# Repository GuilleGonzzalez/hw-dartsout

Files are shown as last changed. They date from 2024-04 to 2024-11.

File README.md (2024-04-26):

# Dartsout

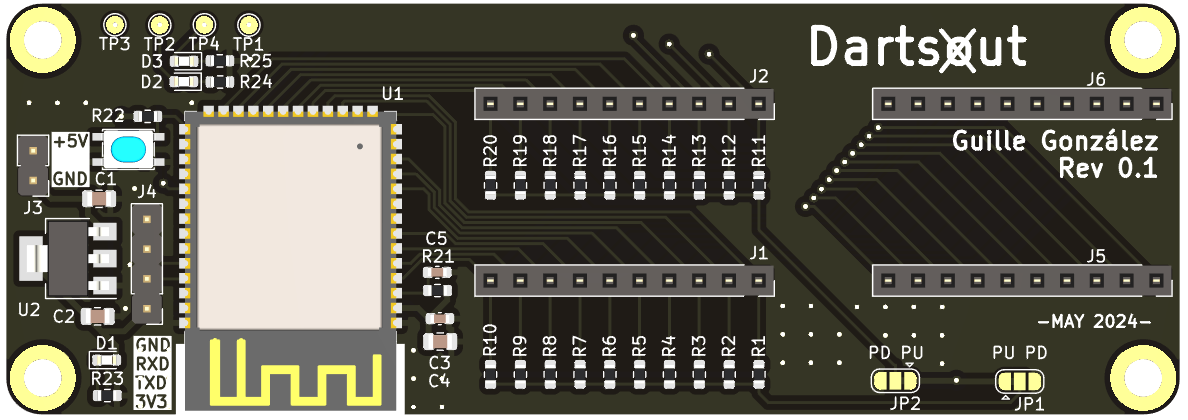
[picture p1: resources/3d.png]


## Description

Dartsout is a pcb designed to replace the control board of commercial dartboards to make them compatible with Dartsout, a darts playing application hosted on a server.

Firmware used in the microcontroller of this device is [dartsout](https://github.com/GuilleGonzzalez/fw-dartsout), writed in C. Is in charge of reading the value pressed by the dart and sending it via WiFi to the Dartsout server.

## Microprocessor

Espressif [ESP32-S2-SOLO](https://www.espressif.com/en/products/modules) module (NRND).

## Connectors

The device has 10-pin connectors with a pitch of 2.54, compatible with the connectors of commercial targets. For the connection, it will be necessary to unsolder the connectors of the target to be modified and solder them on this PCB.

They have been duplicated to be flexible with the target connectors to be modified, as sometimes they are in parallel and sometimes they are on top of each other.

In all cases, pin 1 is the one on the right.

## Pin assignment

| PIN | Func |
| --- | --- |
| GPIO1 | ROW01 |
| GPIO9 | ROW02 |
| GPIO3 | ROW03 |
| GPIO8 | ROW04 |
| GPIO18  | ROW05 |
| GPIO17  | ROW06 |
| GPIO7 | ROW07 |
| GPIO6 | ROW08 |
| GPIO5 | ROW09 |
| GPIO4 | ROW10 |
| GPIO37  | COL01 |
| GPIO36  | COL02 |
| GPIO35  | COL03 |
| GPIO34  | COL04 |
| GPIO33  | COL05 |
| GPIO21  | COL06 |
| GPIO14  | COL07 |
| GPIO13  | COL08 |
| GPIO12  | COL09 |
| GPIO11  | COL10 |
| GPIO11  | COL10 |
| GPIO1 | USER LED 1 |
| GPIO2 | USER LED 2 |

## LEDs

This PCB has 3 LEDs:

- One power LED, indicating that the device is on.
- Two for user control.

# Changelog

All notable changes to this project will be documented in this section.

The format is based on [Keep a Changelog](https://keepachangelog.com/en/1.0.0/)

## [v0.1.0] - 2024-04-26
### Add
First Dartsout version.

## [unreleased] - 2024-04-24

[unreleased]: https://github.com/GuilleGonzzalez/hw-dartsout

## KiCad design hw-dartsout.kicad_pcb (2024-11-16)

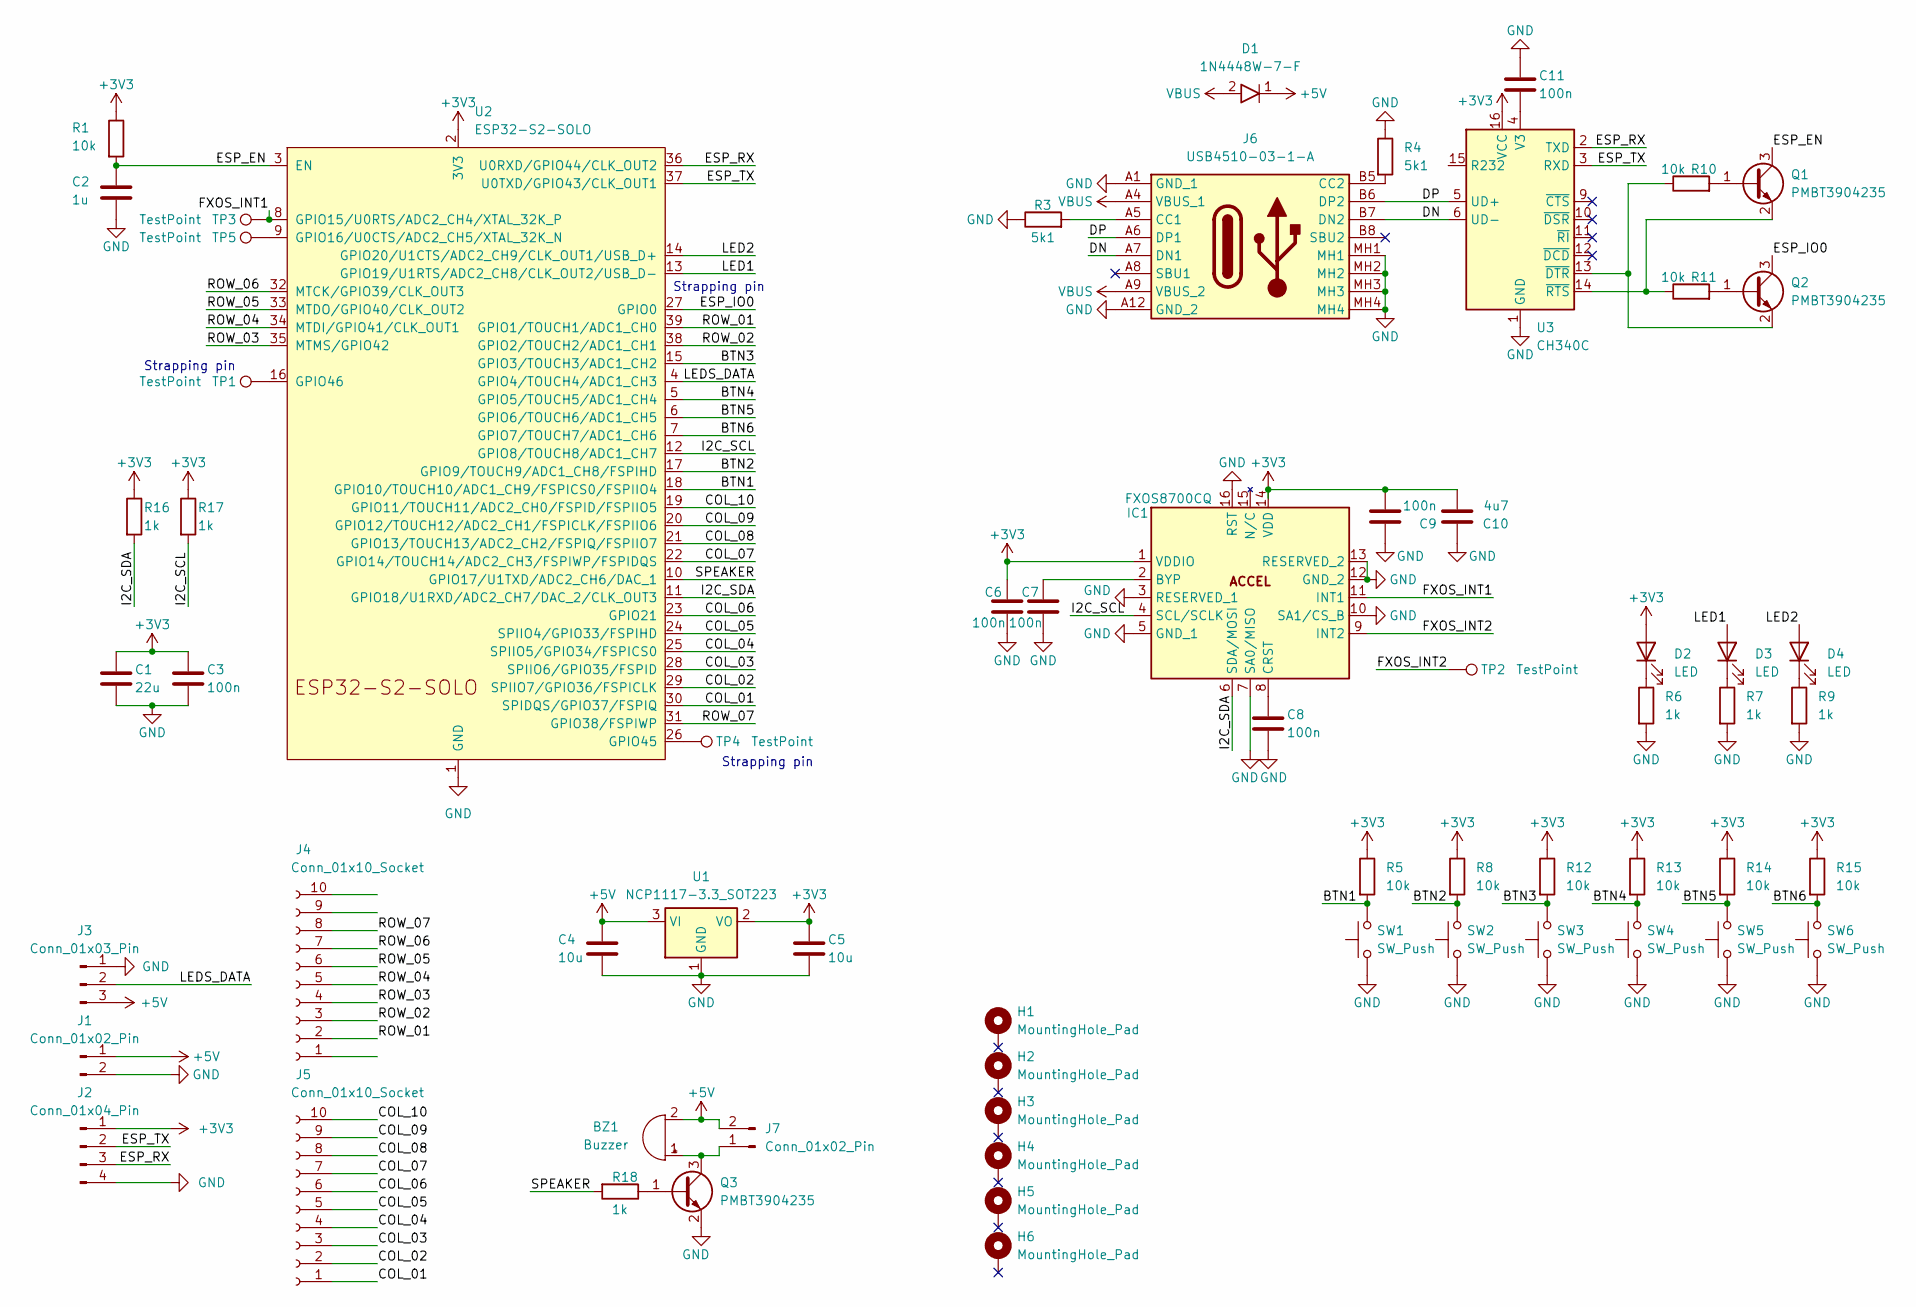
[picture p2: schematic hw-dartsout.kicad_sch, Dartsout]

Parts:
BZ1: Buzzer; Buzzer_12x9.5RM7.6
C1: 22u; C_0805_2012Metric
C2: 1u; C_0603_1608Metric
C3, C6, C7, C8, C9, C11: 100n; C_0603_1608Metric
C4, C5: 10u; C_0805_2012Metric
C10: 4u7; C_0805_2012Metric
D1: 1N4448W-7-F; D_SOD-123; Manufacturer_Part_Number 1N4448W-7-F; Mouser Part Number 621-1N4448W-F
D2, D3, D4: LED; LED_0603_1608Metric
H1, H2, H3, H4, H5, H6: MountingHole_Pad; MountingHole_3.2mm_M3_DIN965_Pad_TopBottom
IC1: FXOS8700CQ; Manufacturer_Part_Number FXOS8700CQ; Mouser Part Number N/A
J1: Conn_01x02_Pin; PinHeader_1x02_P2.54mm_Vertical
J2: Conn_01x04_Pin; PinHeader_1x04_P2.54mm_Vertical
J3: Conn_01x03_Pin; JST_XH_B3B-XH-A_1x03_P2.50mm_Vertical
J4, J5: Conn_01x10_Socket; PinSocket_1x10_P2.54mm_Vertical
J6: USB4510-03-1-A; USB4510031A; Mouser Part Number 640-USB4510031A
J7: Conn_01x02_Pin; PinHeader_1x02_P2.54mm_Horizontal
Q1, Q2, Q3: PMBT3904235; SOT-23; Manufacturer_PN PMBT3904,235
R1, R5, R8, R10, R11, R12, R13, R14, R15: 10k; R_0603_1608Metric
R3, R4: 5k1; R_0603_1608Metric
R6, R7, R9, R16, R17, R18: 1k; R_0603_1608Metric
SW1, SW2, SW3, SW4, SW5, SW6: SW_Push; SW_SPST_PTS810
TP1, TP2, TP3, TP4, TP5: TestPoint; TestPoint_Pad_D1.5mm
U1: NCP1117-3.3_SOT223; SOT-223-3_TabPin2
U2: ESP32-S2-SOLO
U3: CH340C; SOIC-16_3.9x9.9mm_P1.27mm

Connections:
+3V3: C1.1, C3.1, C5.1, C6.1, C9.2, C10.2, D2.2 (A), IC1.1 (VDDIO), IC1.14 (VDD), J2.1, R1.1, R5.1, R8.1, R12.1, R13.1, R14.1, R15.1, R16.1, R17.1, U1.2 (VO), U2.2 (3V3), U3.16 (VCC)
+5V: BZ1.2 (-), C4.1, D1.1, J1.1, J3.3, J7.2, U1.3 (VI)
/BTN1: R5.2, SW1.2, U2.18 (GPIO10/TOUCH10/ADC1_CH9/FSPICS0/FSPIIO4)
/BTN2: R8.2, SW2.2, U2.17 (GPIO9/TOUCH9/ADC1_CH8/FSPIHD)
/BTN3: R12.2, SW3.2, U2.15 (GPIO3/TOUCH3/ADC1_CH2)
/BTN4: R13.2, SW4.2, U2.5 (GPIO5/TOUCH5/ADC1_CH4)
/BTN5: R14.2, SW5.2, U2.6 (GPIO6/TOUCH6/ADC1_CH5)
/BTN6: R15.2, SW6.2, U2.7 (GPIO7/TOUCH7/ADC1_CH6)
/COL_01: J5.1, U2.30 (SPIDQS/GPIO37/FSPIQ)
/COL_02: J5.2, U2.29 (SPIIO7/GPIO36/FSPICLK)
/COL_03: J5.3, U2.28 (SPIIO6/GPIO35/FSPID)
/COL_04: J5.4, U2.25 (SPIIO5/GPIO34/FSPICS0)
/COL_05: J5.5, U2.24 (SPIIO4/GPIO33/FSPIHD)
/COL_06: J5.6, U2.23 (GPIO21)
/COL_07: J5.7, U2.22 (GPIO14/TOUCH14/ADC2_CH3/FSPIWP/FSPIDQS)
/COL_08: J5.8, U2.21 (GPIO13/TOUCH13/ADC2_CH2/FSPIQ/FSPIIO7)
/COL_09: J5.9, U2.20 (GPIO12/TOUCH12/ADC2_CH1/FSPICLK/FSPIIO6)
/COL_10: J5.10, U2.19 (GPIO11/TOUCH11/ADC2_CH0/FSPID/FSPIIO5)
/DN: J6.A7 (DN1), J6.B7 (DN2), U3.6 (UD-)
/DP: J6.A6 (DP1), J6.B6 (DP2), U3.5 (UD+)
/ESP_EN: C2.1, Q1.3, R1.2, U2.3 (EN)
/ESP_IO0: Q2.3, U2.27 (GPIO0)
/ESP_RX: J2.3, U2.36 (U0RXD/GPIO44/CLK_OUT2), U3.2 (TXD)
/ESP_TX: J2.2, U2.37 (U0TXD/GPIO43/CLK_OUT1), U3.3 (RXD)
/FXOS_INT1: IC1.11 (INT1), TP3.1, U2.8 (GPIO15/U0RTS/ADC2_CH4/XTAL_32K_P)
/FXOS_INT2: IC1.9 (INT2), TP2.1
/I2C_SCL: IC1.4 (SCL/SCLK), R17.2, U2.12 (GPIO8/TOUCH8/ADC1_CH7)
/I2C_SDA: IC1.6 (SDA/MOSI), R16.2, U2.11 (GPIO18/U1RXD/ADC2_CH7/DAC_2/CLK_OUT3)
/LED1: D3.2 (A), U2.13 (GPIO19/U1RTS/ADC2_CH8/CLK_OUT2/USB_D-)
/LED2: D4.2 (A), U2.14 (GPIO20/U1CTS/ADC2_CH9/CLK_OUT1/USB_D+)
/LEDS_DATA: J3.2, U2.4 (GPIO4/TOUCH4/ADC1_CH3)
/ROW_01: J4.2, U2.39 (GPIO1/TOUCH1/ADC1_CH0)
/ROW_02: J4.3, U2.38 (GPIO2/TOUCH2/ADC1_CH1)
/ROW_03: J4.4, U2.35 (MTMS/GPIO42)
/ROW_04: J4.5, U2.34 (MTDI/GPIO41/CLK_OUT1)
/ROW_05: J4.6, U2.33 (MTDO/GPIO40/CLK_OUT2)
/ROW_06: J4.7, U2.32 (MTCK/GPIO39/CLK_OUT3)
/ROW_07: J4.8, U2.31 (GPIO38/FSPIWP)
/SPEAKER: R18.2, U2.10 (GPIO17/U1TXD/ADC2_CH6/DAC_1)
GND: C1.2, C2.2, C3.2, C4.2, C5.2, C6.2, C7.1, C8.2, C9.1, C10.1, C11.1, IC1.3 (RESERVED_1), IC1.5 (GND_1), IC1.7 (SA0/MISO), IC1.10 (SA1/CS_B), IC1.12 (GND_2), IC1.13 (RESERVED_2), IC1.16 (RST), J1.2, J2.4, J3.1, J6.A1 (GND_1), J6.A12 (GND_2), J6.MH1, J6.MH2, J6.MH3, J6.MH4, Q3.2, R3.1, R4.1, R6.2, R7.2, R9.2, SW1.1, SW2.1, SW3.1, SW4.1, SW5.1, SW6.1, U1.1 (GND), U2.1 (GND), U2.40 (GND), U2.41 (GND), U3.1 (GND)
unnamed: BZ1.1 (+), J7.1, Q3.3
unnamed: D2.1 (K), R6.1
unnamed: D3.1 (K), R7.1
unnamed: D4.1 (K), R9.1
unnamed: C7.2, IC1.2 (BYP)
unnamed: C8.1, IC1.8 (CRST)
unnamed: J6.A5 (CC1), R3.2
unnamed: J6.B5 (CC2), R4.2
unnamed: Q1.1, R10.2
unnamed: Q2.1, R11.2
unnamed: Q3.1, R18.1
unnamed: TP5.1, U2.9 (GPIO16/U0CTS/ADC2_CH5/XTAL_32K_N)
unnamed: TP4.1, U2.26 (GPIO45)
unnamed: TP1.1, U2.16 (GPIO46)
unnamed: C11.2, U3.4 (V3)
unnamed: Q2.2, R10.1, U3.13 (~DTR)
unnamed: Q1.2, R11.1, U3.14 (~RTS)
VBUS: D1.2, J6.A4 (VBUS_1), J6.A9 (VBUS_2)

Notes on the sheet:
Strapping pin

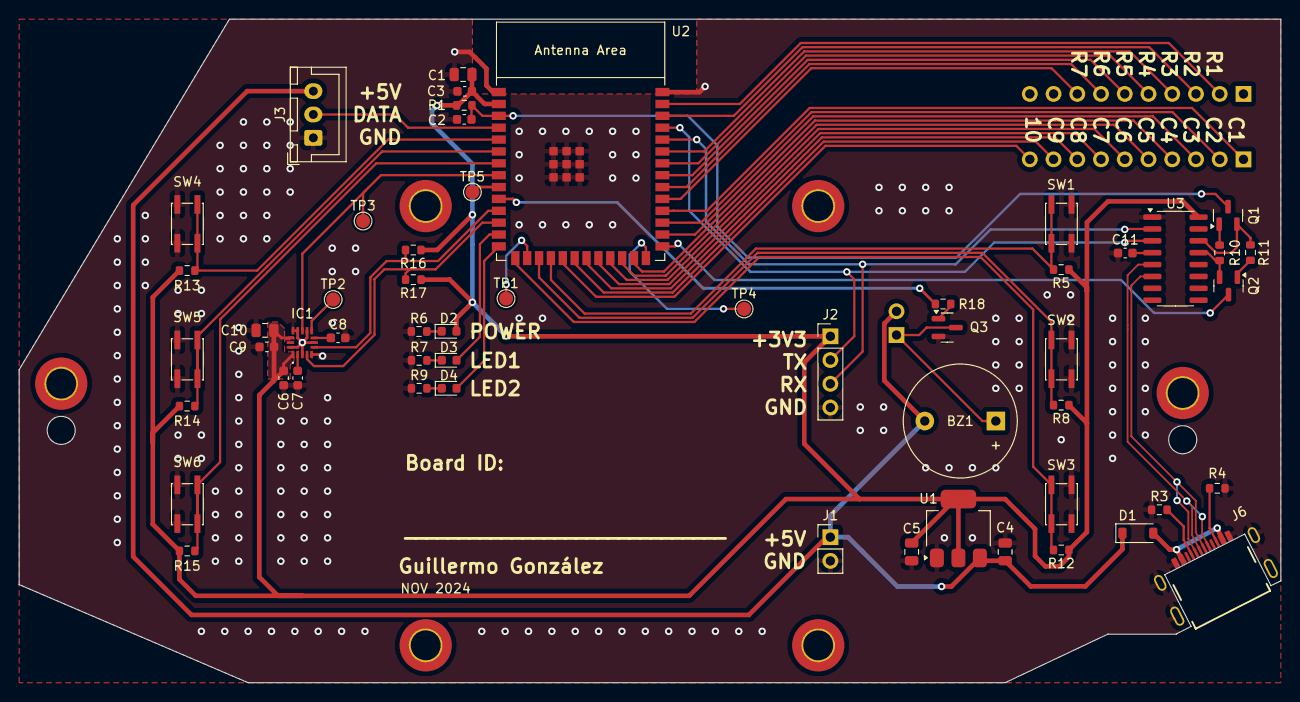
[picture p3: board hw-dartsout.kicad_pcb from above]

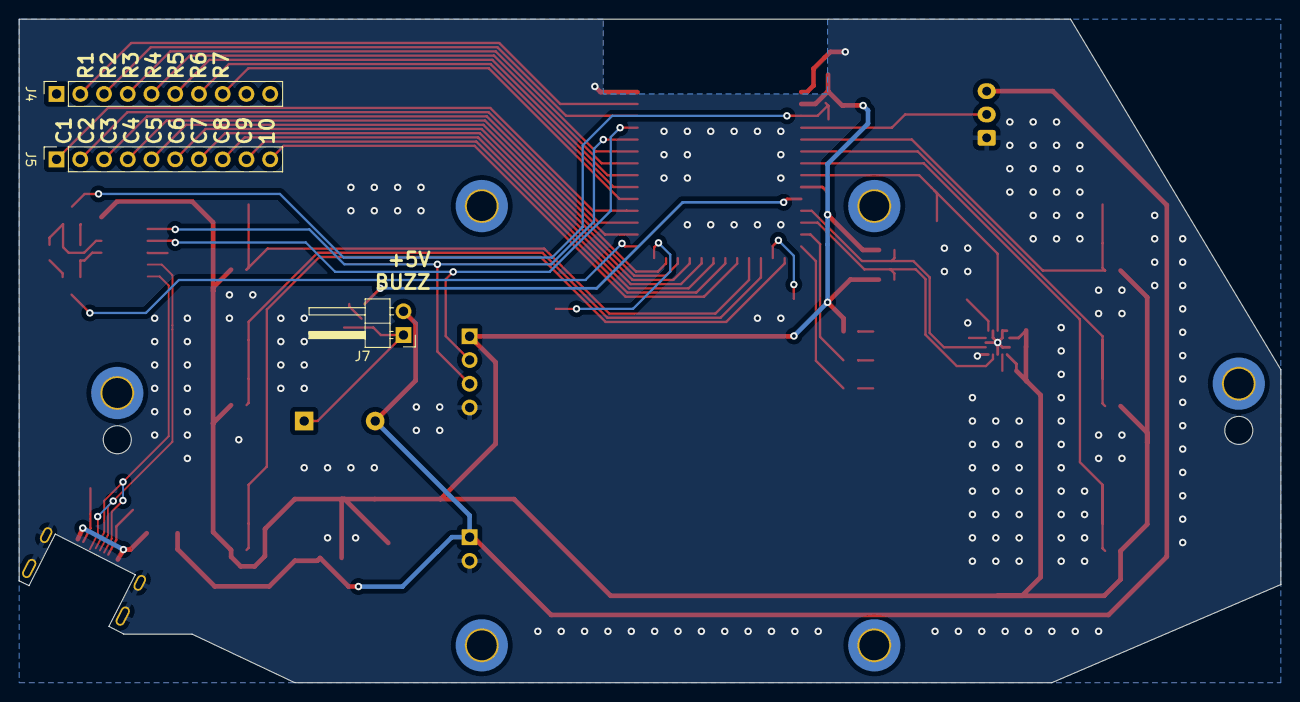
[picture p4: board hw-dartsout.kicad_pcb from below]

Board: 2 copper layers, 135.0 x 71.0 mm, 64 parts (3 on the bottom side), 58 nets.

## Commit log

2024-04-24 Start SCH
    [hw-dartsout.kicad_sch]
2024-04-24 First draft placement and layout
    [hw-dartsout.kicad_pcb, hw-dartsout.kicad_sch]
2024-04-25 PCB routed
    [hw-dartsout.kicad_pcb, hw-dartsout.kicad_sch]
2024-04-26 Finish route, serigrphy and checks
    [hw-dartsout.kicad_pcb, hw-dartsout.kicad_sch]
2024-04-26 Revision 0.1
    [hw-dartsout.kicad_pcb, hw-dartsout.kicad_sch]
2024-11-06 Changed sch and start with layout for next version
    [hw-dartsout.kicad_pcb, hw-dartsout.kicad_sch]
2024-11-16 Add changes for revision 0.2
    [hw-dartsout.kicad_pcb, hw-dartsout.kicad_sch]
